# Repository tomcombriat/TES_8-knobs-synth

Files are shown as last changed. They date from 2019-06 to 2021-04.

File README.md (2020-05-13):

# TES - 8 knobs synth
T. Combriat

8 knobs synths are simple synthesizers based on [Mozzi](https://github.com/sensorium/Mozzi) using STM32 blue pill as the main hardware. Thanks to the computing power of these chips, these synthesizers are able to generate complex polyphonic sounds at 32kHz sampling rate. The aim of this serie is to provide a fixed hardware which can be used for different synthesis methods.

### Synthesizers
* [XORAND](XORAND_poly)
* [FM synth](FM_synth_poly)

***

### Hardware
These synthesizers feature: 
* MIDI input and thru
* 8 knobs for controlling parameters (thus the name), note that one is hardwired for volume control
* 6.35mm audio output (mono)
* standalone power from 3 AA batteries. This ensures cleaner sound thanks to very stable power lines.

PCBs for the chip are single faced and can be easily made if one is able to make 250 microns wide tracks. The mask is provided [here](8knobs_mono) for the mono version.

#### Hardware versions
For now, only one version of this synth has been developped: mono output using the chip PWM and a low-pass 1<sup>st</sup> filter. Other versions, featuring Mozzi HiFi, stereo, DAC outputs may come.

***

### Programming
These synths can be programmed like any other STM32 pills using USB to serial converter. Native USB will usually not work. You will  also need a rather new version of the Arduino IDE with Mozzi installed and modify Mozzi in accordance with the beginning of the sketch or use the [TES forked version of Mozzi](https://github.com/tomcombriat/Mozzi/tree/TES-stable).

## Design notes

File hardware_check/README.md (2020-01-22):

## Hardware check

A simple program to test that the PCB is correct: will print in the Serial monitor MIDI events and the values of the knobs

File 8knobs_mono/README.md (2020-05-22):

## 8 knobs mono

Actual working version of 8 knobs synth. Features an STM32 BluePill, with standard audio output (STANDARD_PLUS 10bits of Mozzi @ 32k)

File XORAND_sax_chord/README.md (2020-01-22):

## TES - XORAND sax
T. Combriat

A version of [XORAND synth](https://github.com/tomcombriat/8_knobs_synth/tree/master/XORAND_poly) to be used with an EWI or the [TESaxophone](https://t-e-s.frama.site/en/tesaxophone).
Differences include:
* Polyphony: 1
* Portamento
* Breath controlled volume and filter
* Buil-it short time double delay

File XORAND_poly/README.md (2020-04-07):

## TES - XORAND poly
T. Combriat

A synthetizer based on bitwise XOR and AND operators. A pure digital synth, outside the fashion for analog… Unpredictable sounds guaranteed!

***

### Specs
* Two meta-oscillators (two oscillators each) continuously adjustables from
  * sin to square for the first one (6)
  * triangle to saw for the second one (5)
* Mix between these two meta-oscillators: amount of each send to the mixing unit (3)
* Mixing unit: continously adjustable from **XOR** to **AND** via standard **add** (7)
* Low-pass filter with adjustable cutoff (4) and aftertouch
* Standard Attack (2) and Release (1) knobs
* Built-in analogic logarithmic volume (V)
* Polyphony: 16 notes
* PitchBend and aftertouch

*Note*: numbers in parenthesis denote the knob number. 

### Compilation options
In order to work properly, this sketch should be compiled with -O3 (fastest) option in the Arduino IDE.
The BluePill must be set to 128MHz clock frequency.
We are at the edge…

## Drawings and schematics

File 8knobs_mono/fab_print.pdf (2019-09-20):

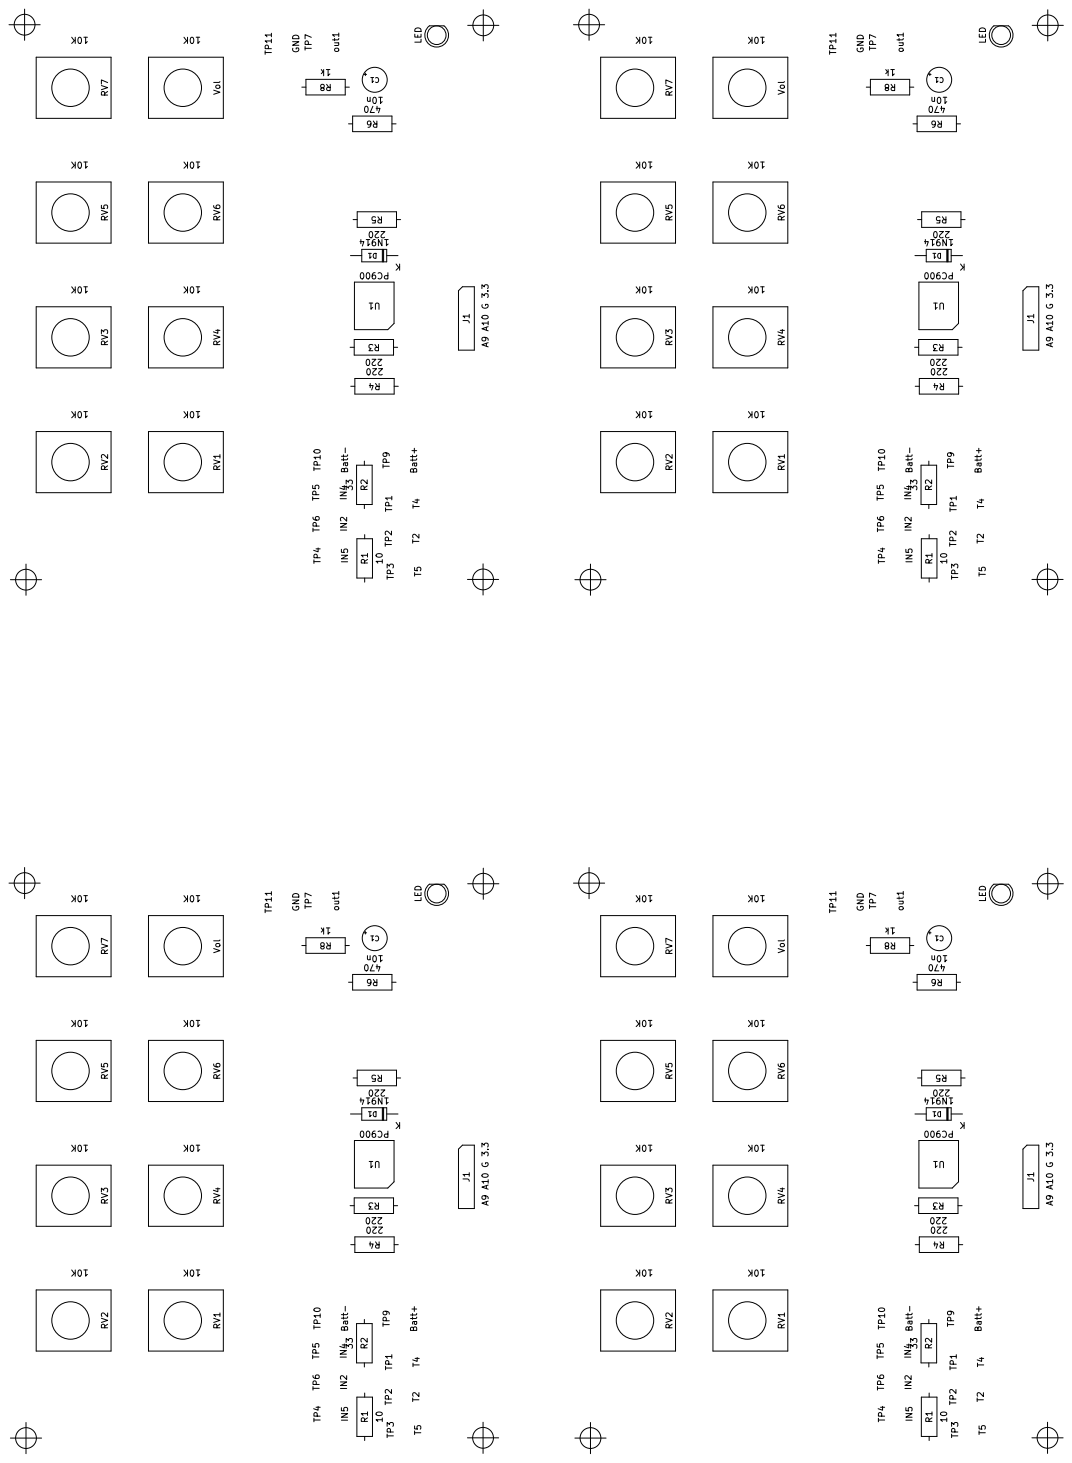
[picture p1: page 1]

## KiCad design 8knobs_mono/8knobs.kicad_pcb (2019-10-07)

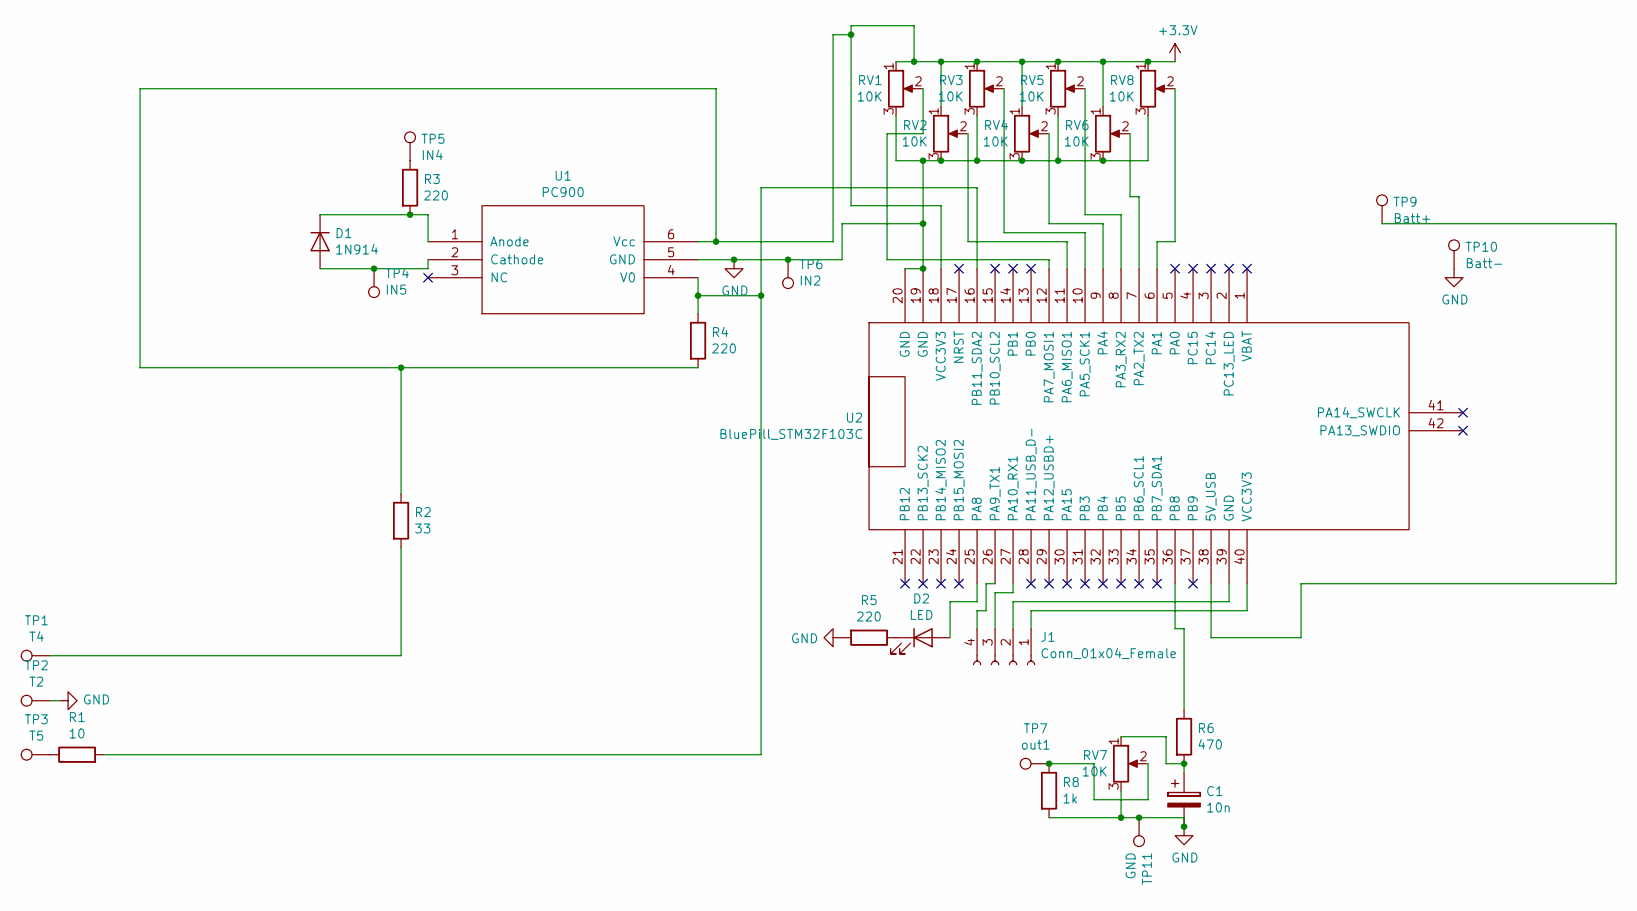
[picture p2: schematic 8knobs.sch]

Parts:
C1: 10n; CP_Radial_D4.0mm_P2.00mm
D1: 1N914; D_DO-35_SOD27_P7.62mm_Horizontal
D2: LED; LED_D3.0mm
J1: Conn_01x04_Female; PinHeader_1x04_P2.54mm_Vertical
R1: 10; R_Axial_DIN0207_L6.3mm_D2.5mm_P7.62mm_Horizontal
R2: 33; R_Axial_DIN0207_L6.3mm_D2.5mm_P7.62mm_Horizontal
R3, R4, R5: 220; R_Axial_DIN0207_L6.3mm_D2.5mm_P7.62mm_Horizontal
R6: 470; R_Axial_DIN0207_L6.3mm_D2.5mm_P7.62mm_Horizontal
R8: 1k; R_Axial_DIN0207_L6.3mm_D2.5mm_P7.62mm_Horizontal
RV1, RV2, RV3, RV4, RV5, RV6, RV7, RV8: 10K; Potentiometer_Alps_RK09K_Single_Vertical
TP1: T4; TestPoint_THTPad_2.5x2.5mm_Drill1.2mm
TP2: T2; TestPoint_THTPad_2.5x2.5mm_Drill1.2mm
TP3: T5; TestPoint_THTPad_2.5x2.5mm_Drill1.2mm
TP4: IN5; TestPoint_THTPad_2.5x2.5mm_Drill1.2mm
TP5: IN4; TestPoint_THTPad_2.5x2.5mm_Drill1.2mm
TP6: IN2; TestPoint_THTPad_2.5x2.5mm_Drill1.2mm
TP7: out1; TestPoint_THTPad_2.5x2.5mm_Drill1.2mm
TP9: Batt+; TestPoint_THTPad_2.5x2.5mm_Drill1.2mm
TP10: Batt-; TestPoint_THTPad_2.5x2.5mm_Drill1.2mm
TP11: GND; TestPoint_THTPad_2.5x2.5mm_Drill1.2mm
U1: PC900
U2: BluePill_STM32F103C

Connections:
+3V3: R2.1, R4.2, RV1.1, RV2.1, RV3.1, RV4.1, RV5.1, RV6.1, RV8.1, U1.6 (Vcc), U2.18 (VCC3V3)
GND: C1.2, R5.2, R8.2, RV1.3, RV2.3, RV3.3, RV4.3, RV5.3, RV6.3, RV7.3, RV8.3, TP2.1, TP6.1, TP10.1, TP11.1, U1.5 (GND), U2.19 (GND), U2.20 (GND)
unnamed: C1.1, R6.2, RV7.1
unnamed: D1.1 (K), R3.2, U1.1 (Anode)
unnamed: D1.2 (A), TP4.1, U1.2 (Cathode)
unnamed: D2.1 (K), R5.1
unnamed: D2.2 (A), U2.25 (PA8)
unnamed: J1.1, U2.40 (VCC3V3)
unnamed: J1.2, U2.39 (GND)
unnamed: J1.3, U2.27 (PA10_RX1)
unnamed: J1.4, U2.26 (PA9_TX1)
unnamed: R1.1, TP3.1
unnamed: R1.2, R4.1, U1.4 (V0), U2.16 (PB11_SDA2)
unnamed: R2.2, TP1.1
unnamed: R3.1, TP5.1
unnamed: R6.1, U2.36 (PB8)
unnamed: R8.1, RV7.2, TP7.1
unnamed: RV1.2, U2.12 (PA7_MOSI1)
unnamed: RV2.2, U2.11 (PA6_MISO1)
unnamed: RV3.2, U2.10 (PA5_SCK1)
unnamed: RV4.2, U2.9 (PA4)
unnamed: RV5.2, U2.8 (PA3_RX2)
unnamed: RV6.2, U2.7 (PA2_TX2)
unnamed: RV8.2, U2.6 (PA1)
unnamed: TP9.1, U2.38 (5V_USB)

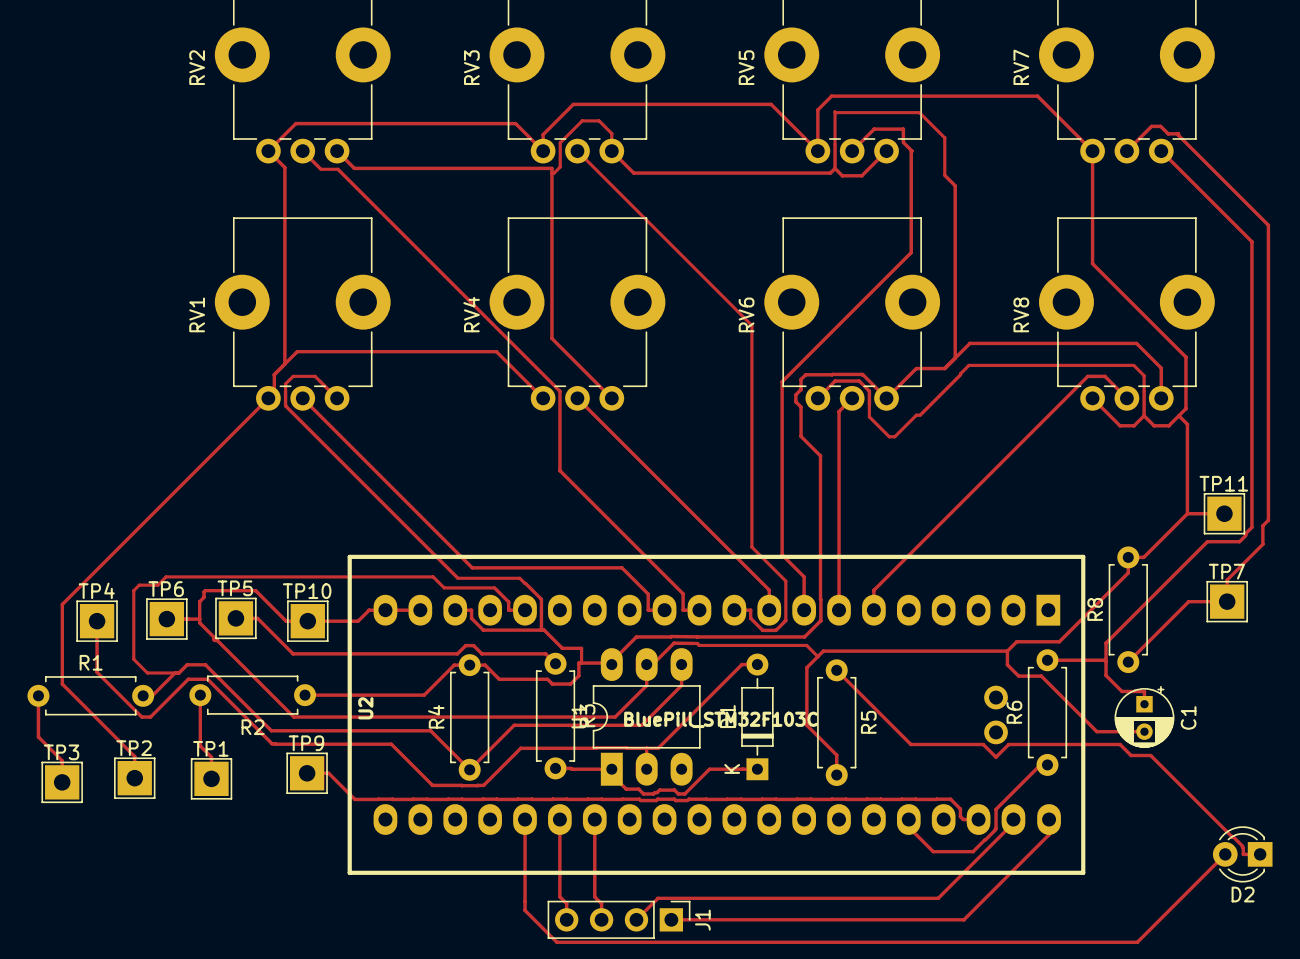
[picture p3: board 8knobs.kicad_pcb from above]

Board: 2 copper layers, 31 parts (0 on the bottom side), 25 nets.

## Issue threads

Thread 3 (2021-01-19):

8 knobs synth and XORAND without MIDI

pirvcb, 2021-01-19:
Hi Thomas.
I toke a look to your really interesting works.
I would like ask you if you have old betas or test sketches about XORAND and 8 knobs synth that you can up.
I'd like try to get out juice without MIDI protocol but using knobs instead. Otherwise, i ask you to suggest me just the right direction to go in deep trough your projects looking to convert MIDI input to analog input.
Thank you!
Davide.
P.S. My Akay EWI is still there.... but i'm just going explore others things.

tomcombriat, 2021-01-20:
Hi,

Unfortunately, I do not have such sketches… My goal was, from the start, to make synths with MIDI support. However, this can be easily modified by assigning the knobs to something else (pitch? velocity? etc…), and keep the "synthesis part" of the XORAND.

Otherwise, I could also suggest to have a look on other projects made with Mozzi. Lot of them are based on AVR chips, so you might need to adjust a few things (AVR outputs 8bits, whereas the BP outputs 10), but I remember that quite a few of them are realized with knobs control. The [gallery](https://sensorium.github.io/Mozzi/gallery/) of Mozzi can be a good start, but also popular websites of videos streaming. Most of these do share their code.

Hope it helps,

pirvcb, 2021-01-20:
Thnak You!

Closed 2021-01-20.

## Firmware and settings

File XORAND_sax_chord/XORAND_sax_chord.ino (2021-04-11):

/*
   Combriat 2020
   To change from mozzi original:
       -   unsigned long update_step_counter;
       -   unsigned long update_steps;
       -   unsigned long num_update_steps;   in ADSR.h (L51)
       -   unsigned long convertMsecToControlUpdateSteps(unsigned int msec){
   return (uint32_t) (((uint32_t)msec*CONTROL_UPDATE_RATE)>>10); // approximate /1000 with shift


*/

// TO BE LOADED
// to be tested : *log* volume = 255*(1-exp(-0.04*breath))  LOADED
// to be tested : *exp* volume = exp(breath/22.9)


#include <MIDI.h>
#include <MozziGuts.h>
#include <Oscil.h>
#include <tables/cos2048_int8.h> // table for Oscils to play
#include <tables/square_no_alias_2048_int8.h>
#include <tables/saw_no_alias_2048_int8.h>
#include <tables/saw2048_int8.h>

#include <tables/triangle2048_int8.h>
#include <mozzi_midi.h>
#include <mozzi_fixmath.h>
#include <Smooth.h>
#include <ADSR.h>
#include <LowPassFilter.h>
#include <AudioDelayFeedback.h>
#include <Portamento.h>
#include "midi_handles.h"

#define POLYPHONY 8
#define CONTROL_RATE 2048 // Hz, powers of 2 are most reliable

#define LED PA8
#define BREATH_LIN
//#define BREATH_LOG
//#define BREATH_EXP



Oscil<COS2048_NUM_CELLS, AUDIO_RATE> aSin[POLYPHONY] = Oscil<COS2048_NUM_CELLS, AUDIO_RATE> (COS2048_DATA);
Oscil<SQUARE_NO_ALIAS_2048_NUM_CELLS, AUDIO_RATE> aSquare[POLYPHONY] = Oscil<SQUARE_NO_ALIAS_2048_NUM_CELLS, AUDIO_RATE>(SQUARE_NO_ALIAS_2048_DATA);
Oscil<TRIANGLE2048_NUM_CELLS, AUDIO_RATE> aTri[POLYPHONY] = Oscil<TRIANGLE2048_NUM_CELLS, AUDIO_RATE>(TRIANGLE2048_DATA);
Oscil<SAW_NO_ALIAS_2048_NUM_CELLS, AUDIO_RATE> aSaw[POLYPHONY] = Oscil<SAW_NO_ALIAS_2048_NUM_CELLS, AUDIO_RATE>(SAW_NO_ALIAS_2048_DATA);
//Oscil<SAW2048_NUM_CELLS, AUDIO_RATE> aSaw[POLYPHONY] = Oscil<SAW2048_NUM_CELLS, AUDIO_RATE>(SAW2048_DATA);
//Oscil<COS2048_NUM_CELLS, CONTROL_RATE> LFO[POLYPHONY] = Oscil<COS2048_NUM_CELLS, CONTROL_RATE> (COS2048_DATA);
Oscil<COS2048_NUM_CELLS, AUDIO_RATE> LFO[POLYPHONY] = Oscil<COS2048_NUM_CELLS, AUDIO_RATE> (COS2048_DATA);


ADSR <AUDIO_RATE, AUDIO_RATE> envelope[POLYPHONY];
ADSR <AUDIO_RATE, AUDIO_RATE> envelope_audio;
LowPassFilter lpf;
Smooth <int> kSmoothInput(0.2f);
Smooth <byte> breath_smooth(0.6f);
//Portamento<CONTROL_RATE> porta;

byte notes[POLYPHONY] = {0};
int wet_dry_mix, modulation[POLYPHONY];
int mix1;
int mix2;
int mix_oscil, cutoff = 0, pitchbend = 0, pitchbend_amp = 2, aftertouch = 0, prev_cutoff = 0, breath_on_cutoff = 0, midi_cutoff = 255;
byte oscil_state[POLYPHONY], oscil_rank[POLYPHONY], runner = 0, volume = 0, delay_volume = 0;
bool sustain = false;
bool mod = true;
bool osc_is_on[POLYPHONY] = {false};
unsigned int chord_attack = 1, chord_release = 1;
byte breath_to_volume[128];
bool toggle = 0;
Q15n16 vibrato;



// Serial1 RX PA10
// Serial2 RX PA3
// Serial3 RX PB11

MIDI_CREATE_INSTANCE(HardwareSerial, Serial3, MIDI);



void set_freq(byte i, bool reset_phase = false)
{

  osc_is_on[i] = true;
  Q16n16 freq = Q16n16_mtof(Q8n0_to_Q16n16(notes[i]) + (pitchbend << 3) * pitchbend_amp);
  //Q16n16 freq = porta.next() + Q16n16_mtof(pitchbend << 4) ; // mettre plutot   Q16n16_mtof((pitchbend << 4) + porta.next())

  //Q16n16 freq = Q16n16_mtof(Q8n0_to_Q16n16(notes[i]));
  //Serial.println(Q16n16_to_float(modulation[i]));
  aSin[i].setFreq_Q16n16(freq);
  aSquare[i].setFreq_Q16n16(freq);
  aTri[i].setFreq_Q16n16(freq);
  aSaw[i].setFreq_Q16n16(freq);


  if (reset_phase) LFO[i].setPhase(0);
}


int three_values_knob(int val, int i)
{
  switch (i)
  {
    case 0:
      {
        if (val > 512) {
          return 0;
        }
        else return (512 - val);
      }
    case 1:
      {
        if (val < 512) return val;
        else return 1024 - val;
      }
    case 2:
      {
        if (val < 512 ) return 0;
        else return val - 512;
      }
  }
}




void setup() {
  pinMode(LED, OUTPUT);
  digitalWrite(LED, HIGH);
  pinMode(PA1, INPUT);
  pinMode(PA2, INPUT);
  pinMode(PA3, INPUT);
  pinMode(PA4, INPUT);
  pinMode(PA5, INPUT);
  pinMode(PA6, INPUT);
  pinMode(PA7, INPUT);

  for (byte i = 0; i < POLYPHONY; i++)
  {
    aSaw[i].setPhase(2048 >> 2 );
    envelope[i].setADLevels(128, 128);
    envelope[i].setTimes(1, 1, 65000, 10);
  }

  for (int i = 0; i < 128; i++)
  {
#ifdef BREATH_LOG
    breath_to_volume[i] = 255 * (1 - exp(-0.04 * i));
#endif
#ifdef BREATH_LIN
    breath_to_volume[i] = 2 * i;
#endif
#ifdef BREATH_EXP
    breath_to_volume[i] = exp(i / 23.);
#endif

  }
  // envelope_audio.setADLevels(128, 128);
  //envelope_audio.setTimes(1, 1, 65000, 100);
  lpf.setResonance(25);



  MIDI.setHandleNoteOn(HandleNoteOn);
  MIDI.setHandleNoteOff(HandleNoteOff);
  MIDI.setHandleControlChange(HandleControlChange);
  MIDI.setHandlePitchBend(HandlePitchBend);
  MIDI.setHandleAfterTouchChannel(HandleAfterTouchChannel);

  //Serial.begin(115200);


  MIDI.begin(MIDI_CHANNEL_OMNI);
  delay(100);
  digitalWrite(LED, LOW);
  delay(100);
  digitalWrite(LED, HIGH);
  delay(100);

  MIDI.turnThruOff (); //for speed
  startMozzi(CONTROL_RATE);
  digitalWrite(LED, LOW);

}







void loop() {
  audioHook();
}







void updateControl() {

  while (MIDI.read());
  //set_freq(0);
  //Serial.println(volume);
  if (toggle)
  {
    mix1 =  mozziAnalogRead(PA6) >> 4;
    mix2 =  mozziAnalogRead(PA5) >> 4;
    wet_dry_mix = mozziAnalogRead(PA7) >> 2;  // goos to 1024
    mix_oscil = mozziAnalogRead(PA3) >> 4 ;
  }
  else
  {
    chord_release = mozziAnalogRead(PA1) >> 1 ;
    chord_attack = mozziAnalogRead(PA2) >> 1 ;
    breath_on_cutoff = kSmoothInput(mozziAnalogRead(PA4) >> 4);
    cutoff = ((breath_on_cutoff * volume) >> 7 ) + midi_cutoff;

    if (cutoff > 255) cutoff = 255;

    if (cutoff != prev_cutoff)
    {
      lpf.setCutoffFreq(cutoff);
      prev_cutoff = cutoff;
    }
  }
  toggle = !toggle;

  /*
    for (byte i = 0; i < POLYPHONY; i++)
    {
      modulation[i] = (LFO[i].next());
    }
  */
  // MIDI.read();
}

int updateAudio() {

  long sample = 0;
  //envelope_audio.update();



  int breath_next = breath_smooth.next(breath_to_volume[volume]); // this could be done in updatecontrol() maybe? for speed? And the following also
  if (breath_next == 0)
  {
    for (byte i = 0; i < POLYPHONY; i++)
    {
      envelope[i].noteOff();
      osc_is_on[i] = false; // so that chord do not fade out during next note afer a short pause
      oscil_state[i] = 0;   // everybody reset
    }
  }


  //vibrato = (Q15n16) 32 * LFO[0].next();
  vibrato = ((Q15n16)  LFO[0].next()) << 4;
  for (byte i = 0; i < POLYPHONY; i++)
  {
    envelope[i].update();
    int env_next = envelope[i].next();  // for enveloppe to roll even if it is not playing
    if (envelope[i].playing() && osc_is_on[i])
    {
      long partial_sample = 0;

      int aSin_next;
      int aSquare_next;
      int aTri_next;
      int aSaw_next;


      if (!mod)
      {
        aSin_next = aSin[i].next();
        aSquare_next = aSquare[i].next();
        aTri_next = aTri[i].next();
        aSaw_next = aSaw[i].next();
      }
      else
      {
        aSin_next = aSin[i].phMod(vibrato);
        aSquare_next = aSquare[i].next();
        aTri_next = aTri[i].phMod(vibrato);
        aSaw_next = aSaw[i].next();
      }


      int oscil1 = (((aSin_next * (255 - mix1) + aSquare_next * (mix1)) >> 8 ) * (255 - mix_oscil)) >> 8 ;
      int oscil2 = (((aTri_next * (255 - mix2) + aSaw_next * (mix2)) >> 8 ) * mix_oscil) >> 8;

      int dry = oscil1 + oscil2;
      int wet1 = (oscil1 xor oscil2);
      int wet2 = oscil1 & oscil2;


      partial_sample += ((three_values_knob(wet_dry_mix, 0) >> 1) * wet1) >> 8 ;
      partial_sample += ((three_values_knob(wet_dry_mix, 1) >> 1) * dry) >> 8 ;
      partial_sample += ((three_values_knob(wet_dry_mix, 2) >> 1) * wet2) >> 8 ;
      // sample += ((wet_dry_mix) * wet) >> 8;

      //sample += (((((partial_sample * (breath_to_volume[volume])) >> 8) * modulation[i]) >> 8) * envelope_audio.next()) >> 8 ; //is played actively now
      //sample += (((((partial_sample * (breath_to_volume[volume])) >> 8) * modulation[i]) >> 7) ); //is played actively now
      //sample += envelope_audio.next() * (((((partial_sample * (breath_smooth.next(breath_to_volume[volume]))) ) * modulation[i]) >> 16)); //is played actively now

      //sample +=  (partial_sample * (breath_next * envelope[i].next()) >> 2)  >> 10;
      sample += (partial_sample * env_next) >> 3;

      //else sample += (((partial_sample * (envelope[i].next())) >> 8) * modulation[i]) >> 9 ;  //is played actively now
    }
  }

  sample = (sample * breath_next) >> 10 ;


  // int env = envelope[0].next();
  //int env = envelope_audio.next();



  /*
    sample += (((delay_level * aDel.next(byte(sample >> 2), ((Q16n16) 2048) << 16 )) >> 8) * env) >> 8 ;
    sample += (((delay_level * aDel2.next(byte(sample >> 2), ((Q16n16) 1801) << 16 )) >> 10) * env) >> 8 ;

  */

  sample = lpf.next(sample);
  if (sample > 511)
  {
    digitalWrite(LED, HIGH);

    sample = 511;
  }
  else if (sample < -511)
  {
    sample = -511;
  }
  else if (digitalRead(LED)) digitalWrite(LED, LOW);


  return sample;

}

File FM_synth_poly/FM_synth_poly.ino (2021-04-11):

/*
   Combriat 2018
   To change from mozzi original:
       -   unsigned long update_step_counter;
       -   unsigned long update_steps;
       -   unsigned long num_update_steps;   in ADSR.h (L51)
       -   unsigned long convertMsecToControlUpdateSteps(unsigned int msec){
   return (uint32_t) (((uint32_t)msec*CONTROL_UPDATE_RATE)>>10); // approximate /1000 with shift


*/



#include <MIDI.h>
#include <MozziGuts.h>
#include <Oscil.h>
#include <tables/cos2048_int8.h> // table for Oscils to play
#include <tables/square_no_alias_2048_int8.h>
#include <mozzi_midi.h>
#include <mozzi_fixmath.h>
#include <EventDelay.h>
#include <Smooth.h>
#include <ADSR.h>
#include <LowPassFilter.h>
#include "midi_handles.h"

#define POLYPHONY 16
#define CONTROL_RATE 512 // Hz, powers of 2 are most reliable

#define LED PA8

//Oscil<COS2048_NUM_CELLS, AUDIO_RATE> aCarrier[2] = {Oscil<COS2048_NUM_CELLS, AUDIO_RATE>(COS2048_DATA),Oscil<COS2048_NUM_CELLS, AUDIO_RATE>(COS2048_DATA)};
Oscil<COS2048_NUM_CELLS, AUDIO_RATE> aCarrier[POLYPHONY] = {Oscil<COS2048_NUM_CELLS, AUDIO_RATE>(COS2048_DATA)};
Oscil<COS2048_NUM_CELLS, AUDIO_RATE> aModulator[POLYPHONY] = {Oscil<COS2048_NUM_CELLS, AUDIO_RATE>(COS2048_DATA)};
Oscil<COS2048_NUM_CELLS, AUDIO_RATE> subOscill[POLYPHONY] = {Oscil<COS2048_NUM_CELLS, AUDIO_RATE>(COS2048_DATA)};
Oscil<SQUARE_NO_ALIAS_2048_NUM_CELLS, AUDIO_RATE> subOscill_sq[POLYPHONY] = {Oscil<SQUARE_NO_ALIAS_2048_NUM_CELLS, AUDIO_RATE>(SQUARE_NO_ALIAS_2048_DATA)};
Oscil<COS2048_NUM_CELLS, CONTROL_RATE> LFO(COS2048_DATA);
Oscil<COS2048_NUM_CELLS, CONTROL_RATE> subLFO(COS2048_DATA);

ADSR <AUDIO_RATE, AUDIO_RATE> envelope[POLYPHONY];
LowPassFilter lpf;

Q16n16 deviation;
Q8n8 mod_index;
Q16n16 carrier_freq[POLYPHONY], mod_freq;
Q8n8 mod_to_carrier_ratio ;//= float_to_Q8n8(3.f);
int sub_volume;
int pitchbend = 0;
int mod, mod_sub;
byte notes[POLYPHONY];
byte runner, aftertouch = 0, modulationW = 127;
byte oscil_state[POLYPHONY], oscil_rank[POLYPHONY];
unsigned long last_sustain_time;
bool sustain = false;
int mix_sub;


Smooth <int> kSmoothInput(0.2f);

// Serial1 RX PA10
// Serial2 RX PA3
// Serial3 RX PB11

MIDI_CREATE_INSTANCE(HardwareSerial, Serial3, MIDI);


void set_freq(byte i)
{
  carrier_freq[i] = Q16n16_mtof(Q8n0_to_Q16n16(notes[i]) + (pitchbend << 4));
  mod_freq = ((carrier_freq[i] >> 8) * mod_to_carrier_ratio)  ;
  aCarrier[i].setFreq_Q16n16(carrier_freq[i]);
  subOscill[i].setFreq_Q16n16(carrier_freq[i]);
  subOscill_sq[i].setFreq_Q16n16(carrier_freq[i]);
  aModulator[i].setFreq_Q16n16(mod_freq);
}



void setup() {
  pinMode(PA1, INPUT);
  pinMode(PA2, INPUT);
  pinMode(PA3, INPUT);
  pinMode(PA4, INPUT);
  pinMode(PA5, INPUT);
  pinMode(PA6, INPUT);
  pinMode(PA7, INPUT);
  pinMode(LED, OUTPUT);

  for (byte i = 0; i < POLYPHONY; i++)
  {
    oscil_state[i] = 0;   //0: unactive  1: playing   2: playing thanks to sustain
    oscil_rank[i] = 0;
  }
  runner = 0;

  for (byte i = 0; i < POLYPHONY; i++) envelope[i].setADLevels(255, 255);
  mod_to_carrier_ratio = float_to_Q8n8(3.f);
  lpf.setResonance(20);


  MIDI.setHandleNoteOn(HandleNoteOn);
  MIDI.setHandleNoteOff(HandleNoteOff);
  MIDI.setHandleControlChange(HandleControlChange);
  MIDI.setHandlePitchBend(HandlePitchBend);
  MIDI.setHandleAfterTouchChannel(HandleAfterTouchChannel);

  MIDI.begin(1);
  //Serial.begin(115200);
  MIDI.turnThruOff ();
  startMozzi(CONTROL_RATE);
}

void loop() {
  audioHook();
}

void updateControl() {

  while (MIDI.read());



  sub_volume = mozziAnalogRead(PA7) >> 2;
  mod_index = (kSmoothInput.next(mozziAnalogRead(PA3)));
  deviation = mod_index << 8 ;

  envelope[runner].setTimes(mozziAnalogRead(PA2), 1, 65000, mozziAnalogRead(PA1));
  runner++;
  if (runner >= POLYPHONY) runner = 0;

  LFO.setFreq_Q16n16((Q16n16) (mozziAnalogRead(PA6) << 8 ));
  subLFO.setFreq_Q16n16((Q16n16) (mozziAnalogRead(PA5) << 8 ));

  mod = (400 + LFO.next()) >> 4;
  mod_sub   = (350 + subLFO.next()) >> 4;

  mix_sub = (mozziAnalogRead(PA4) >> 4 );

  if ((int) (modulationW << 1) + (aftertouch) < 255) lpf.setCutoffFreq((modulationW << 1) + (aftertouch) );
  else lpf.setCutoffFreq(255);



}

int updateAudio() {
  int sample = 0;
  for (byte i = 0; i < POLYPHONY; i++)
  {
    envelope[i].update();
    Q15n16 modulation = deviation * aModulator[i].next() >> 8;
    sample += (int)   (envelope[i].next() * (((((aCarrier[i].phMod(modulation)  ) * mod) >> 2)      + ((((sub_volume * (((255 - mix_sub) * subOscill[i].next() + (mix_sub) * subOscill_sq[i].next()) >> 8)) >> 8) * mod_sub) >> 4)) >> 8)  >> 2)  ;
  }
  sample = lpf.next(sample);
  if (sample > 511)
  {
    digitalWrite(LED, HIGH);
    sample = 511;
  }
  else if (sample < -511) sample = -511;
  return sample;
}

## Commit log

2019-06-24 Add kicad files
2019-06-24 first test with arduino -> LPF not low enough
    [1row.kicad_pcb, 2rows.kicad_pcb, 8knobs.dsn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]
2019-07-11 Soft clip and note velocity taken into account
2019-08-09 Correction to FM synth, add of digital_Mix synth
    [FM_synth_poly.ino, midi_handles.ino]
2019-09-20 Sax (EWI) version of XORAND, corrected scheduler of XORAND, corrected fabrication mask
    [XORAND_sax.ino, midi_handles.ino]
2019-10-07 v1.1 of 8knobs mono: - corrected wrong connection to battery - easier PCB manufacturing
    [8knobs.dsn, 8knobs.kicad_pcb, 8knobs.sch]
2019-10-23 update to v1.1 for PCB mask
2019-11-21 Corrected header in XORAND Corrected unwanted access to serial in Xorand
    [XORAND_poly.ino]
2020-01-22 Removed old version
    [1row.kicad_pcb, 2rows.kicad_pcb, 8knobs.dsn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]
2020-02-18 Modified LFO for vibrato, check for overflow before reverb
    [XORAND_sax.ino, midi_handles.ino]
2020-03-05 Modified vibrato: faster, smaller
    [XORAND_sax.ino]
2020-04-07 Switched to no_alia saw wave
2020-04-07 Added vibrato mode, can be enabled, or not, at the beginning of the sketch
    [XORAND_poly.ino, midi_handles.ino]
2020-04-15 Added different LED behavior on startup to differentiate the two versions of XORAND_SAX
2020-05-24 Replaced chord_attack, broken by previous commit
    [midi_handles.ino]
2020-06-10 Update FM_synth_poly.ino
    Added braces to fix compile error
    [FM_synth_poly.ino]
2020-06-15 Update XORAND_poly.ino
    Adjusted serial port to match schematic
2020-06-15 Update FM_synth_poly.ino
    Updated serial port to match schematic
2020-06-15 Update XORAND_sax.ino
    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
2020-06-15 Update XORAND_sax_chord.ino
    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
